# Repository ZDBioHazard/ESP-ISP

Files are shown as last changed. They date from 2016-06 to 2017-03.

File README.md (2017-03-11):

ESP-ISP
=======

This is just a simple programming jig for the ESP-12 module.

When putting this device together, use <=40-mil pogo pins for the ESP pins.
You can then place this device on top of a ESP-12 unit to access it's serial port.
(Be careful not to short any of the pogo pins on the metal can though. It can be tricky!)

* `P1` is normal FTDI header. 5V should work.
* `SW1` is a reset switch. Hold it down for >5s to bring `GPIO0` low and release to start flash mode.
* `D5` should light up when `GPIO0` is low.
* `D3` is a power indicator.
* `D2` should light up when the ESP is receiving serial data.

Check the schematic for the parts list.

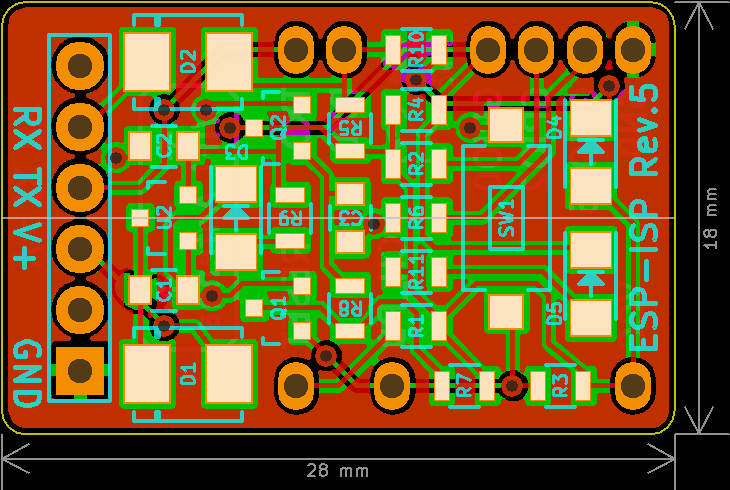
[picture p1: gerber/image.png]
Image of Board


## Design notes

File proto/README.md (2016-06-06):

This folder contains prototyping documents. Usually these are files for
[Paul Falstad's circuit simulator](http://www.falstad.com/circuit/circuitjs.html).

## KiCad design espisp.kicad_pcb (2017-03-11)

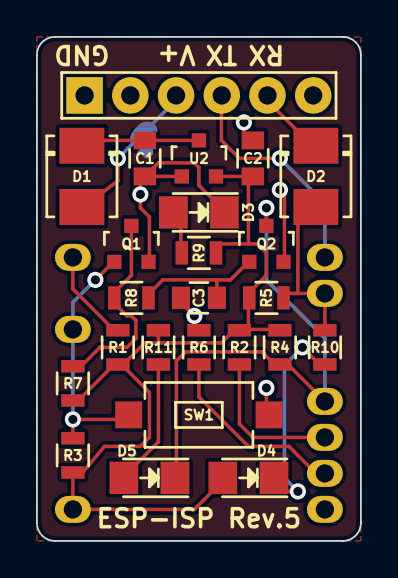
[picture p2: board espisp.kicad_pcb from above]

Board: 2 copper layers, 18.0 x 28.0 mm, 25 parts (0 on the bottom side), 17 nets.

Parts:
C1, C2: 1uF; C_0805
C3: 2.2uF; C_0805
D1, D2: 1N5819; DO-214BA
D3, D4: GREEN; LED_1206
D5: RED; LED_1206
P1: FTDI_BASIC; Pin_Header_Simple_1x06
Q1, Q2: 2N7002; SOT-23
R1, R2, R3, R4, R5, R6: 10K; R_0805
R7, R8: 1M; R_0805
R9, R10, R11: 220; R_0805
SW1: RESET; SMD_PUSHBUTTON_3.6x6.0mm
U1: ESP-12; ESP-12-ISP
U2: XC6206; SOT-23

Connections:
+3V3: C2.1, D4.2, R1.1, R2.1, R3.2, R4.1, R5.2, R7.1, R9.2, R11.1, U1.8, U2.2
/CH_PD: Q1.1, R3.1, SW1.2, U1.3
/GPIO0: D5.1, Q2.3, R4.2, U1.12
/GPIO2: R2.2, U1.11
/GPIO15: R6.1, U1.10
/RESET: R1.2, U1.1
/RXD: D2.2, R5.1, R10.2, U1.15
/RXD_5V: D2.1, P1.5
/TXD: P1.4, U1.16
/VIN_5V: D1.2, P1.3
GND: C1.2, C2.2, C3.2, D3.1, P1.1, Q1.2, Q2.2, R6.2, SW1.1, U1.9, U2.1
unnamed: C1.1, D1.1, U2.3
unnamed: C3.1, Q2.1, R8.2
unnamed: D3.2, R9.1
unnamed: D4.1, R10.1
unnamed: D5.2, R11.2
unnamed: Q1.3, R7.2, R8.1

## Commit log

2016-06-15 Changed FLASH button to a general GPIO0 button.
    First manufacturing.
    [espisp.kicad_pcb, espisp.sch]
2016-07-28 Combine RESET and GPIO0 into one button. (Untested)
    Pressing the button should reset the MCU. Pressing and holding the
    button for ~5 seconds should make it enter flash mode upon release.
    Take a look at /proto/flash.txt to see it in action.
    [espisp.kicad_pcb, espisp.sch]
2017-02-23 Update the schematic to use the new 'switches' library.
    [espisp.sch]
2017-02-23 Change the 41mil holes to 40mil holes.
    [espisp.kicad_pcb]
2017-03-11 Placement tweaking and full reroute. (Rev. 5)
    * Moved the power LED near the power components.
    * All polarized components have the same orientation.
    * Extended the rim so the board can be held down easier.
    * Moved vias out from under components to make them easier to place.
    [espisp.kicad_pcb]
2017-03-11 Added the gerber files and an image for reference.
    [espisp-B.Cu.gbl, espisp-B.Mask.gbs, espisp-B.SilkS.gbo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]
